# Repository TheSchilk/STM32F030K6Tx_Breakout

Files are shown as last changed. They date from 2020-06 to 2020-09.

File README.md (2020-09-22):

# STM32F030K6Tx Breakout

A very simple breakout board for the STM32F030K6Tx MCU. 

Philipp Schilk 2020

https://github.com/TheSchilk/STM32F030K6Tx_Breakout

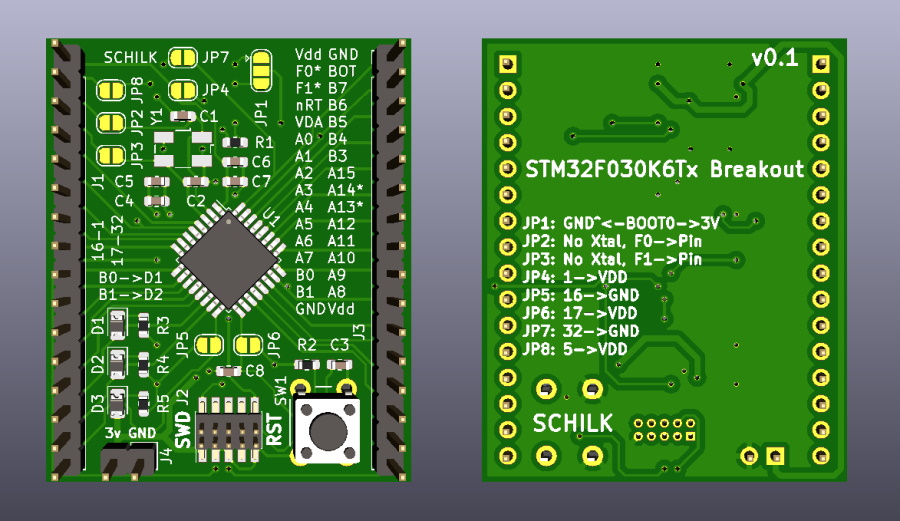
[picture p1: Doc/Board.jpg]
Board


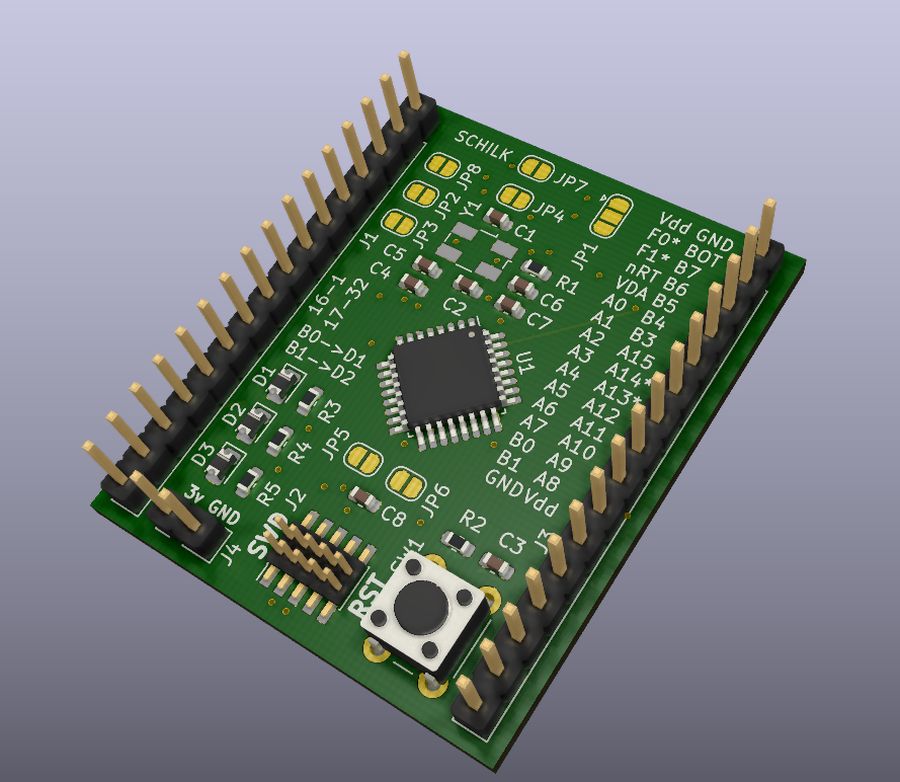
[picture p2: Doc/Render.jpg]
3D Render


## Overview

Besides SWD, 2 LEDs, space for a crystal and other supporting circuitry,
there are bells and whistles.

I did however aim to expose as much functionality of the STM as possible:
The crystal is optional and the IO can be exposed with two jumpers if needed.
Also the VDDA Supply can be separated from VDD if a separate supply is wanted.

In fact, with the right jumper configuration this board can serve as a direct
LQFP32 breakout board with all pins exposed and not set connections.

Because I hate nothing more than digging through PDFs to find out what
pins the LEDs where connected to again, I included as much information
as possible in the silkscreen. 

## Features on Board:

**ARM SWD**:  
Connector footprint can accept both an SMD and a TH programming header. 

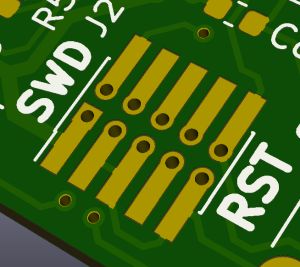
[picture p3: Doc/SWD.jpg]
SWD Connector


See [TheSchilk/KiCad_Devices](https://github.com/TheSchilk/KiCad_Devices) for footprint.

**2 LEDs**:
Connected to pins PB0 and PB1

## Compatibility 

According to CubeMX this breakout should also be compatible with:
 - STM32F031K6Tx
 - STM32F051K4Tx
 - STM32F051K6Tx
 - STM32F051K8Tx
 - STM32F042K4Tx
 - STM32F042K6Tx

But that is untested. Please double check the pinout. 

## Jumper Configuration

Here is what the Jumpers do:

JP1: Connects BOOT0 to either GND (indicated by a small arrow) or VDD, both through R1.
JP2: Connects pin F0 of the STM to the breakout header. Should only be set when not
     using a crystal.
JP3: Connects pin F1 of the STM to the breakout header. Should only be set when not
     using a crystal.
JP4: Connects pin 1 of MCU (VDD) to shared VDD  
JP5: Connects pin 16 of MCU (GND) to shared GND  
JP6: Connects pin 17 of MCU (VDD) to shared VDD  
JP7: Connects pin 32 of MCU (GND) to shared GND   
JP8: Connects pin 5 of MCU (VDD) to shared VDD  

Which means, to use this as a STM breakout:  
Set the following jumpers: JP4  JP5  JP6  JP7  JP8  

If you want a straight LQFP Breakout:
Set the following jumpers: JP2 JP3.

## Pinouts

With an STM32F030K6Tx the pinout is as follows:

| *Pin* | *Function* | *Pin* | *Function* |
|-|-|-|-|
| 1 | Vdd  | 32 |  GND |
| 2 | F0 (1) | 31 | BOOT0 |
| 3 | F1 (1) | 30 | PB7 |
| 4 | nRST  | 29 | PB6 |
| 5 | VDDA  | 28 | PB5 |
| 6 | PA0  | 27 | PB4 |
| 7 | PA1  | 26 | PB3 |
| 8 | PA2  | 25 | PA15 |
| 9 | PA3  | 24 | PA14 |
| 10 | PA4 | 23 | PA13 (3) |
| 11 | PA5 | 22 | PA12 (3) |
| 12 | PA6 | 21 | PA11 |
| 13 | PA7 | 20 | PA10 |
| 14 | PB0 (2) | 19 | PA9 |
| 15 | PB1 (2) | 18 | PA8 |
| 16 | GND | 17 | GND |

(1): Crystal
(2): LEDs
(3); SWD

## Releases 
See [Github releases](https://github.com/TheSchilk/STM32F030K6Tx_Breakout/releases) for:  
    - Gerbers  
    - Schematic  
    - Interactive HTML BOM

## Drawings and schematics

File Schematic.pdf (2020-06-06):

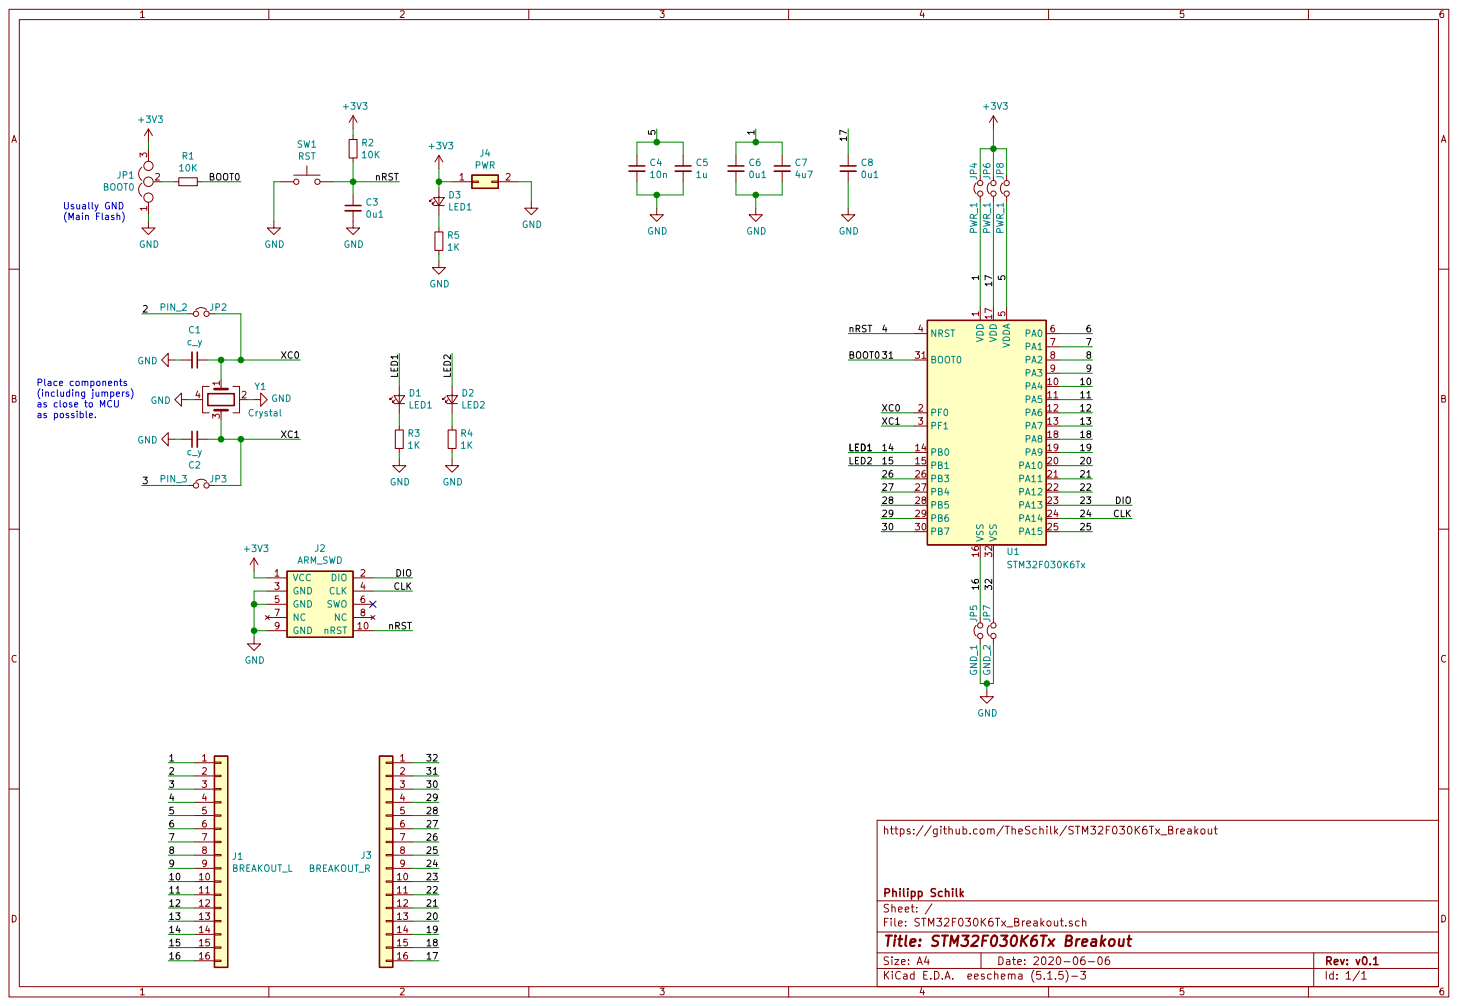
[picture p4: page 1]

26 Place components
(including jumpers) as close to MCU as possible.

https://github.com/TheSchilk/STM32F030K6Tx_Breakout

File: STM32F030K6Tx_Breakout.sch Sheet: / Philipp Schilk

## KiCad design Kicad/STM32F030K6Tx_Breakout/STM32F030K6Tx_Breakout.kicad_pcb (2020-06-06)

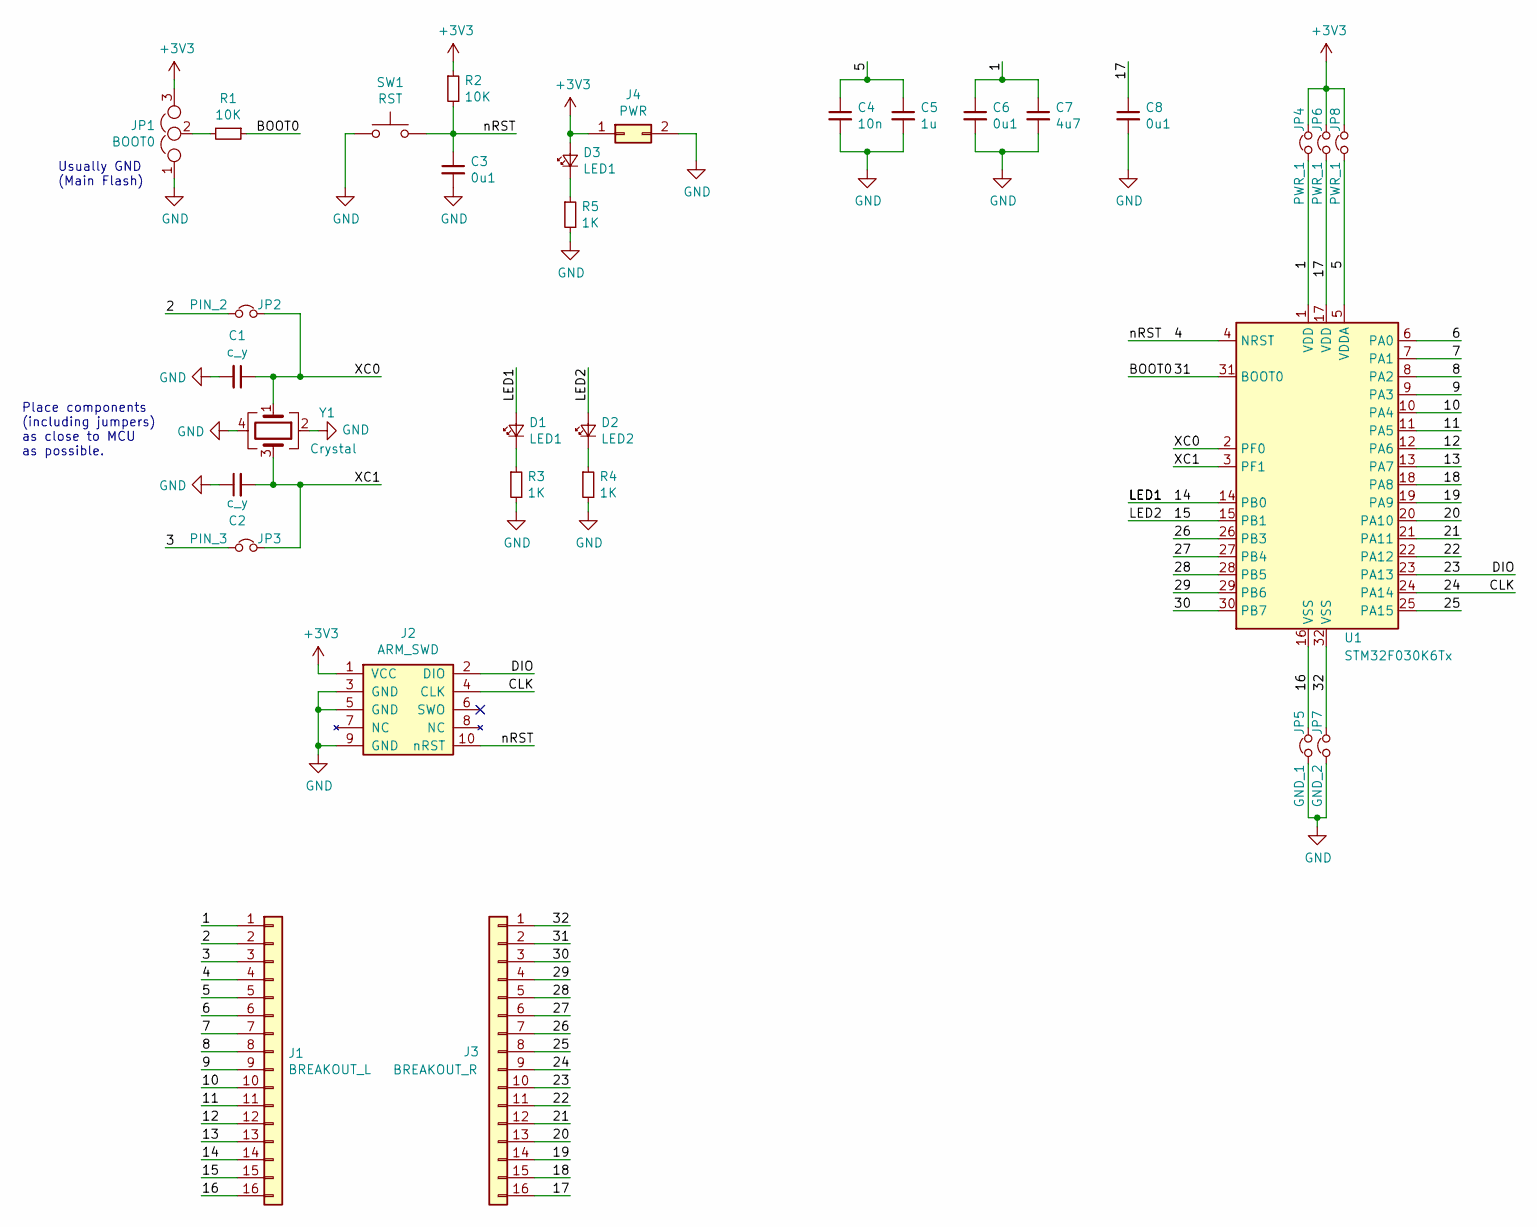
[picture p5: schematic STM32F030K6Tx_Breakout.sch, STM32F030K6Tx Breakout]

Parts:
C1, C2: c_y; C_0603_1608Metric
C3, C6, C8: 0u1; C_0603_1608Metric
C4: 10n; C_0603_1608Metric
C5: 1u; C_0603_1608Metric
C7: 4u7; C_0603_1608Metric
D1, D3: LED1; D_0805_2012Metric
D2: LED2; D_0805_2012Metric
J1: BREAKOUT_L; PinHeader_1x16_P2.54mm_Vertical
J2: ARM_SWD; ARM_SWD_SMD_TH
J3: BREAKOUT_R; PinHeader_1x16_P2.54mm_Vertical
J4: PWR; PinHeader_1x02_P2.54mm_Vertical
JP1: BOOT0; SolderJumper-3_P1.3mm_Open_RoundedPad1.0x1.5mm
JP2: PIN_2; SolderJumper-2_P1.3mm_Open_RoundedPad1.0x1.5mm
JP3: PIN_3; SolderJumper-2_P1.3mm_Open_RoundedPad1.0x1.5mm
JP4, JP6, JP8: PWR_1; SolderJumper-2_P1.3mm_Open_RoundedPad1.0x1.5mm
JP5: GND_1; SolderJumper-2_P1.3mm_Open_RoundedPad1.0x1.5mm
JP7: GND_2; SolderJumper-2_P1.3mm_Open_RoundedPad1.0x1.5mm
R1, R2: 10K; R_0603_1608Metric
R3, R4, R5: 1K; R_0603_1608Metric
SW1: RST; SW_PUSH_6mm
U1: STM32F030K6Tx; LQFP-32_7x7mm_P0.8mm
Y1: Crystal; Crystal_SMD_EuroQuartz_MJ-4Pin_5.0x3.2mm

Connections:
+3V3: D3.2 (A), J2.1 (VCC), J4.1, JP1.3, JP4.2, JP6.2, JP8.2, R2.1
/1: C6.1, C7.1, J1.1, JP4.1, U1.1 (VDD)
/2: J1.2, JP2.1
/3: J1.3, JP3.1
/4: C3.1, J1.4, J2.10 (nRST), R2.2, SW1.2, U1.4 (NRST)
/5: C4.1, C5.1, J1.5, JP8.1, U1.5 (VDDA)
/6: J1.6, U1.6 (PA0)
/7: J1.7, U1.7 (PA1)
/8: J1.8, U1.8 (PA2)
/9: J1.9, U1.9 (PA3)
/10: J1.10, U1.10 (PA4)
/11: J1.11, U1.11 (PA5)
/12: J1.12, U1.12 (PA6)
/13: J1.13, U1.13 (PA7)
/14: D1.2 (A), J1.14, U1.14 (PB0)
/15: D2.2 (A), J1.15, U1.15 (PB1)
/16: J1.16, JP5.2, U1.16 (VSS)
/17: C8.1, J3.16, JP6.1, U1.17 (VDD)
/18: J3.15, U1.18 (PA8)
/19: J3.14, U1.19 (PA9)
/20: J3.13, U1.20 (PA10)
/21: J3.12, U1.21 (PA11)
/22: J3.11, U1.22 (PA12)
/23: J2.2 (DIO), J3.10, U1.23 (PA13)
/24: J2.4 (CLK), J3.9, U1.24 (PA14)
/25: J3.8, U1.25 (PA15)
/26: J3.7, U1.26 (PB3)
/27: J3.6, U1.27 (PB4)
/28: J3.5, U1.28 (PB5)
/29: J3.4, U1.29 (PB6)
/30: J3.3, U1.30 (PB7)
/31: J3.2, R1.1, U1.31 (BOOT0)
/32: J3.1, JP7.2, U1.32 (VSS)
/XC0: C1.1, JP2.2, U1.2 (PF0), Y1.1
/XC1: C2.2, JP3.2, U1.3 (PF1), Y1.3
GND: C1.2, C2.1, C3.2, C4.2, C5.2, C6.2, C7.2, C8.2, J2.3 (GND), J2.5 (GND), J2.9 (GND), J4.2, JP1.1, JP5.1, JP7.1, R3.2, R4.2, R5.2, SW1.1, Y1.2, Y1.4
unnamed: D1.1 (K), R3.1
unnamed: D2.1 (K), R4.1
unnamed: D3.1 (K), R5.1
unnamed: JP1.2, R1.2

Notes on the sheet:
Usually GND (Main Flash)
Place components (including jumpers) as close to MCU as possible.

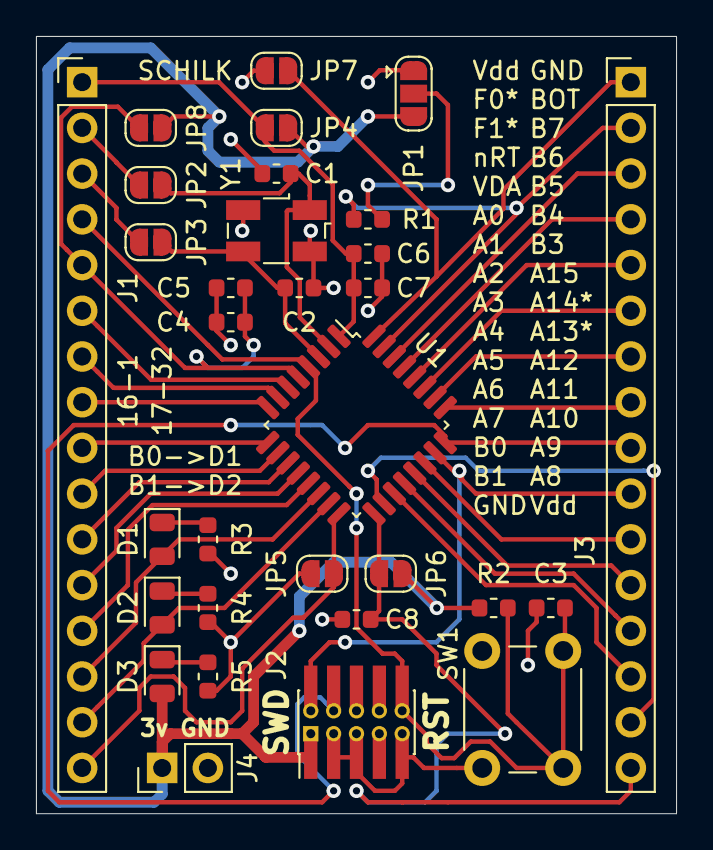
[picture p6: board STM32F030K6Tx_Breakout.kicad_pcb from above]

Board: 2 copper layers, 35.6 x 43.2 mm, 31 parts (0 on the bottom side), 40 nets.

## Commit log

2020-06-06 Added v0.1
    [STM32F030K6Tx_Breakout-B_Cu.gbr, STM32F030K6Tx_Breakout-B_Mask.gbr, STM32F030K6Tx_Breakout-B_Paste.gbr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]
2020-09-22 Added Interactive BOM, reorderd Files.
    [STM32F030K6Tx_Breakout-B_Cu.gbr, STM32F030K6Tx_Breakout-B_Mask.gbr, STM32F030K6Tx_Breakout-B_Paste.gbr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]
